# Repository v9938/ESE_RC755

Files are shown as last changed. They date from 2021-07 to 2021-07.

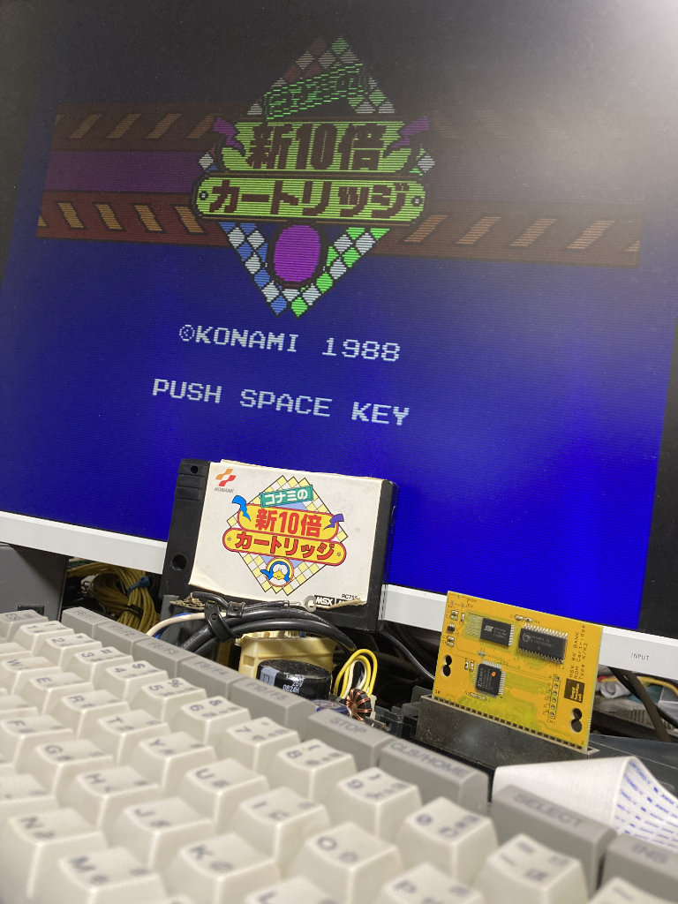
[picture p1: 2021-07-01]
photo01.jpg

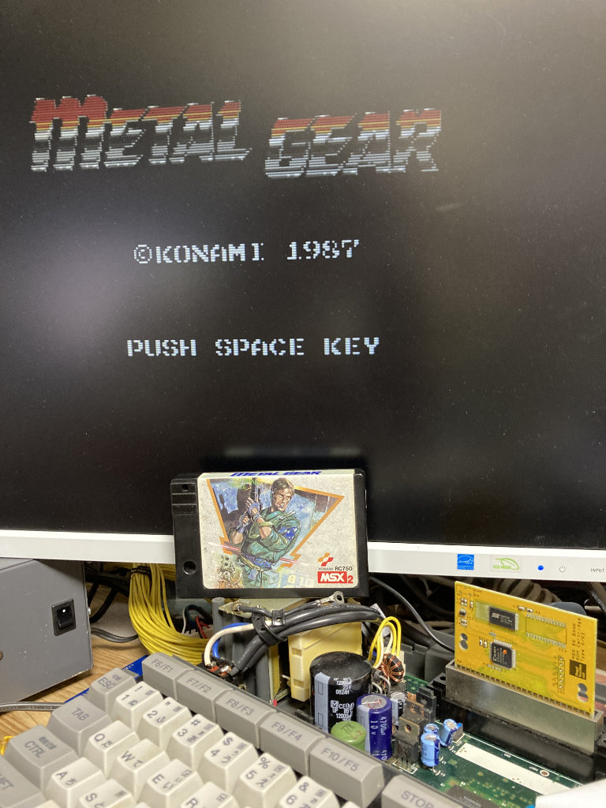
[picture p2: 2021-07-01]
photo02.jpg

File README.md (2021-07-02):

# MSX用カードリッジ KONAMI4互換<BR>Flashカードリッジ 似非RC755
KONAMI8Kバンク切り替え(KONAMI4)互換のカードリッジです。<BR>
KONAMI VRC007431互換のCPLDを搭載しており、「1Mbit+FRAM版」/「4Mbit版」 の2つのVersionがあります。<BR>
※SCCは付いていません。<BR>
<BR>
「1Mbit+FRAM版は、「新10倍カードリッジ」(GAME MASTER2)と同一バンク構成になっており、<BR>
 SRAMバッテリ切れの同カセットの救済用として使用する事ができます。<BR>
<BR>
各カセットは、Boothにて頒布しています。<BR>
https://ifc.booth.pm/items/3092101 
https://ifc.booth.pm/items/3092120

## ■ メモリマップ

KONAMI4と同様の仕様です。0x4000-5FFFの空間はBANK0固定なのに注意してください。

| Page (8kB) | Switching address | Initial segment | 
| --- | --- | --- |
| 4000h ~ 5FFFh  | 5000h (mirrors: 5001h ~ 57FFh) | 0  (FIXED) | 
| 6000h ~ 7FFFh  | 7000h (mirrors: 7001h ~ 77FFh) | 1 | 
| 8000h ~ 9FFFh  | 9000h (mirrors: 9001h ~ 97FFh) | 2 | 
| A000h ~ BFFFh  | B000h (mirrors: B001h ~ B7FFh) | 3 |

<BR>

| BIT7 | BIT6 | BIT5 | BIT4 | BIT3 | BIT2 | BIT1 | BIT0 |
| ---- | ---- | ---- | ---- | ---- | ---- | ---- | ---- |
| Unused | Unused | Segment[5] | Segment[4] | Segment[3] | Segment[2] | Segment[1] | Segment[0] |

Bit 0 ~ 5 = Segment number <BR>
Bit 6 ~ 7 = Unused <BR>
<BR>
F-RAMが有効の場合は下記の通りです。<BR>
| BIT7 | BIT6 | BIT5 | BIT4 | BIT3 | BIT2 | BIT1 | BIT0 |
| ---- | ---- | ---- | ---- | ---- | ---- | ---- | ---- |
| Unused | Unused | SRAM Segment | SRAM/ROM | Segment[3] | Segment[2] | Segment[1] | Segment[0] |

Bit 0 ~ 3 = Segment number <BR>
Bit 4 = 1 to select the SRAM (writable on page B000h ~ BFFFh only) <BR>
Bit 5 = SRAM segment select (two segments of 4kB available) <BR>
Bit 6 ~ 7 = Unused <BR>
<BR>
参考：
https://www.msx.org/wiki/MegaROM_Mappers#Game_Master_2_.28Konami.29

<BR>
下記Pageについては、Flash書き込みの為にBIT7 Flash controlが拡張されています。<BR>
  
| Page (8kB) | Switching address | Initial segment | 
| --- | --- | --- |
| A000h ~ BFFFh (mirror: 2000h ~ 3FFFh) | B000h (mirrors: B001h ~ B7FFh) | 3 |

<BR>
  
| BIT7 | BIT6 | BIT5 | BIT4 | BIT3 | BIT2 | BIT1 | BIT0 |
| ---- | ---- | ---- | ---- | ---- | ---- | ---- | ---- |
| Flash | Unused | Segment[5] | Segment[4] | Segment[3] | Segment[2] | Segment[1] | Segment[0] |

Bit 0 ~ 5 = Segment number <BR>
Bit 6 = Unused <BR>
Bit 7 = Flash control<BR>
<BR>
F-RAMが有効の場合は下記の通りです。<BR>
| BIT7 | BIT6 | BIT5 | BIT4 | BIT3 | BIT2 | BIT1 | BIT0 |
| ---- | ---- | ---- | ---- | ---- | ---- | ---- | ---- |
| Flash | Unused | SRAM Segment | SRAM/ROM | Segment[3] | Segment[2] | Segment[1] | Segment[0] |

Bit 0 ~ 3 = Segment number <BR>
Bit 4 = 1 to select the SRAM (writable on page B000h ~ BFFFh only) <BR>
Bit 5 = SRAM segment select (two segments of 4kB available) <BR>
Bit 6 = Unused <BR>
Bit 7 = Flash control<BR>
<BR>
## ■ Flashの制御方法
書き込みモードにするために、0xA000-BFFFに0x80を書き込んでください。<BR>
Flashのコントロールアドレス2AAAhは4AAAh・コントロールアドレス5555hは5555hにマッピングされます。<BR>
書き込みには6000h ~ 7FFFhの領域を使ってください。他の領域では書き込みができない可能性があります。<BR>
<BR>
本製品は従来使用していたAMD系のFlashではなく、SST系を使用しています。<BR>
CMD体系は、AMD系とほぼ同じなのですが、CMDアドレスが違います。<BR>
また、BUSYの出方などもAMD系と異なるため注意してください。<BR>
  
 | Page 4 | A000h - AFFFh (A000h used) set bit7 = 1'b1  |  Set Flash Write mode | 
 | ------ | ------------------------------------------- | ------------------ | 
 | Page 1 | 4000h - 4fffh = Flash Address 2000 - 2fffh (BA1) MSX:4AAAh  |  Flash:2AAAh |
 | Page 1 | 5000h - 5fffh = Flash Address 5000 - 5fffh (BA2) MSX:5555h  |  Flash:5555h |

CMD例：
1. Set Flash mode         : 0xA000 = 0x80
1. Page Select            : 0x6000 = Segment
1. Flash Byte-Program 1st : 0x5555 = 0xAA
1. Flash Byte-Program 2nd : 0x4AAA = 0x55
1. Flash Byte-Program 3rd : 0x5555 = 0xA0
1. Write Data             : 0x6000～0x7fff = data
1. Page Reselect          : 0x6000 = Segment

参考：
https://www.microchip.com/wwwproducts/en/SST39SF010A
<BR>

## ■ Flash書き込みプログラム
書き込みプログラムとして、eseRC755を同梱しています。 
いずれかのスロットに当該カードリッジを挿入し、以下コマンドを実行してください。<BR>
`>eseRC755.com [書き込みをしたいROM File]`<BR>
<BR>
ソースコードは、z88dkでコンパイル可能です。コンパイルオプションは下記になります。<BR>
`zcc +msx -create-app -subtype=msxdos -lmsxbios  main.c -o eseRC755.com`<BR>

## ■ 頒布基板について
「1Mbit+FRAM版」/「4Mbit版」 の2つのVersionがあります。<BR>
IC1にICが付いているのが「1Mbit+FRAM版」、ICが無いものが「4Mbit版」になります<BR>
<BR>
出荷時は検査用の動作プログラムが書き込んであります。<BR>
動作完了後、[e]キーを押すことで当該プログラムを消去する事が可能です。<BR>

J1をカットしてSW1を追加することで、ROMの切り離しが可能です。後差しが気になる場合に追加してください。<BR>
推奨パーツ：SW1 IS-1245T-G [Switronic] (秋月電子扱い）<BR>
<BR>
回路図およびガーバファイルが必要な場合は同梱ファイルを参考にしてください。<BR>
※ソフト頒布などで使用する場合はご相談頂ければ、別途製造対応可能です。<BR>
<BR>
## ■ CPLDについて
CPLD Xillix XC9536XLに書き込んであるデータは「1Mbit+FRAM版」/「4Mbit版」で異なります。<BR>
RTL上のUSE_MRAMを変更することでそれぞれのVersionを作成可能です。<BR>
<BR>

## ■ カードリッジシェルについて
推奨はRGRさんのTransparent Cartridge Shell for MSX Konami-styleになります。<BR>
https://retrogamerestore.com/store/msx_cart_shell/
<BR>
シェル同梱版も、上記製品を使用しています。<BR>
輸入と製造都合で若干の小傷がある場合があります。あらかじめご了承ください。<BR>
<BR>
頒布基板はASCII仕様のいくつかのシェルタイプに対応していますが、<BR>
すべてのタイプには対応していません。ご了承ください。<BR>

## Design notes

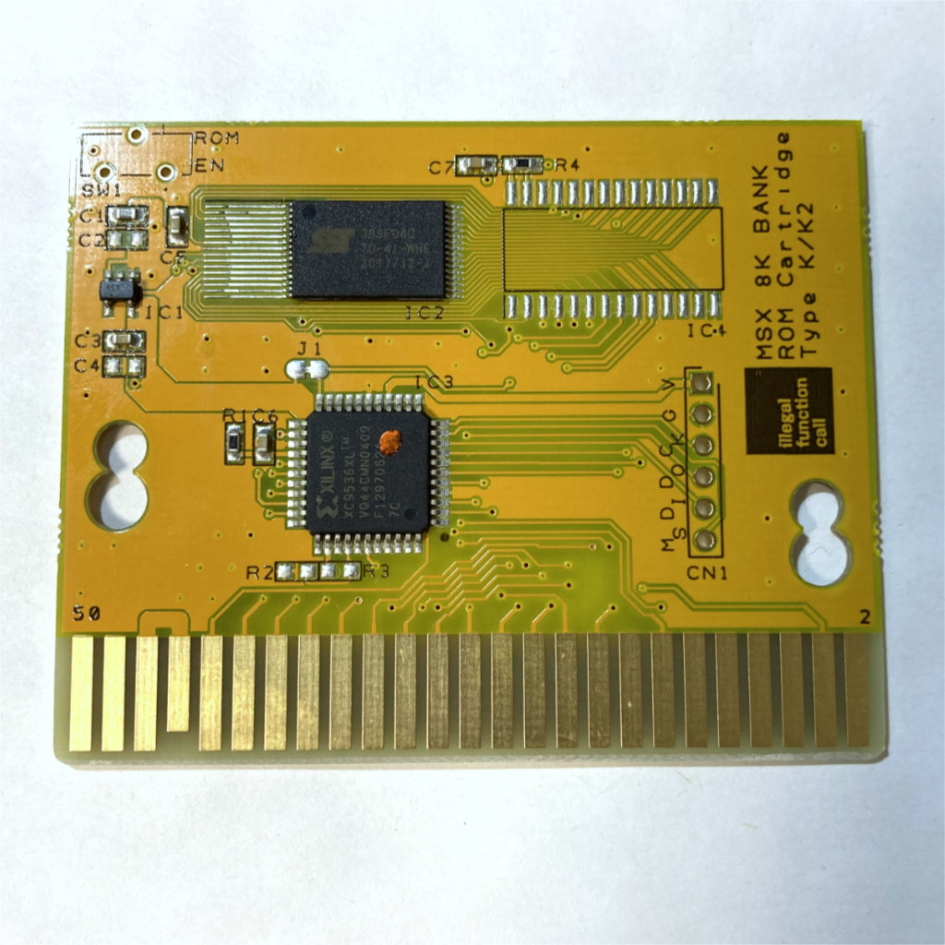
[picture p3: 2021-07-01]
PCB/PCBwoMRAM.jpg

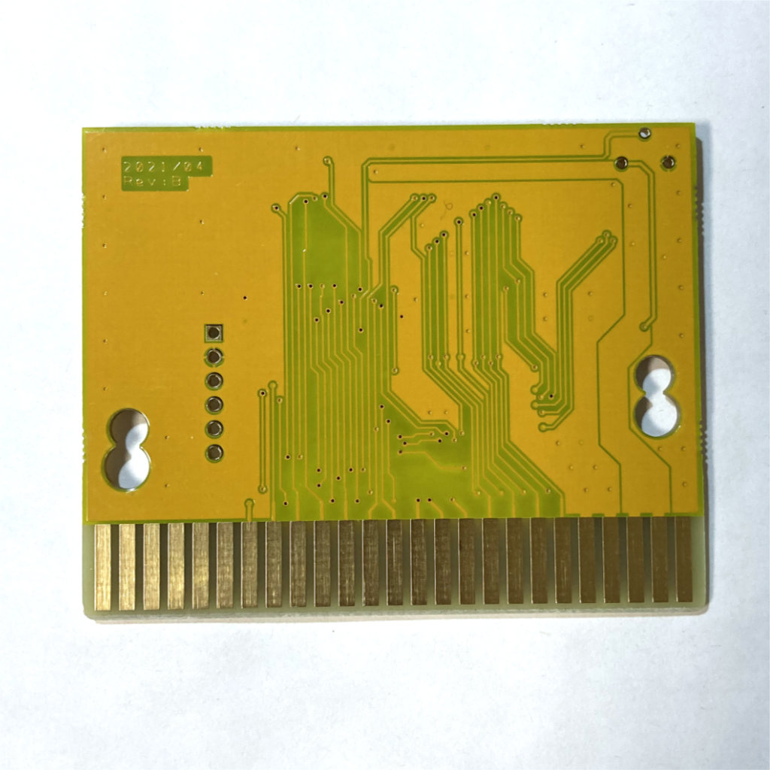
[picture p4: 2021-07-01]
PCB/PCBwMRAM2.jpg

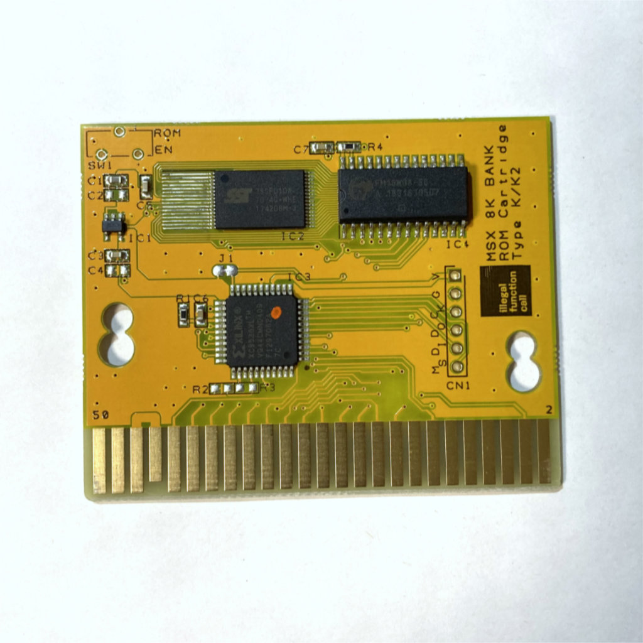
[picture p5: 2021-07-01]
PCB/PCBwMRAM.jpg

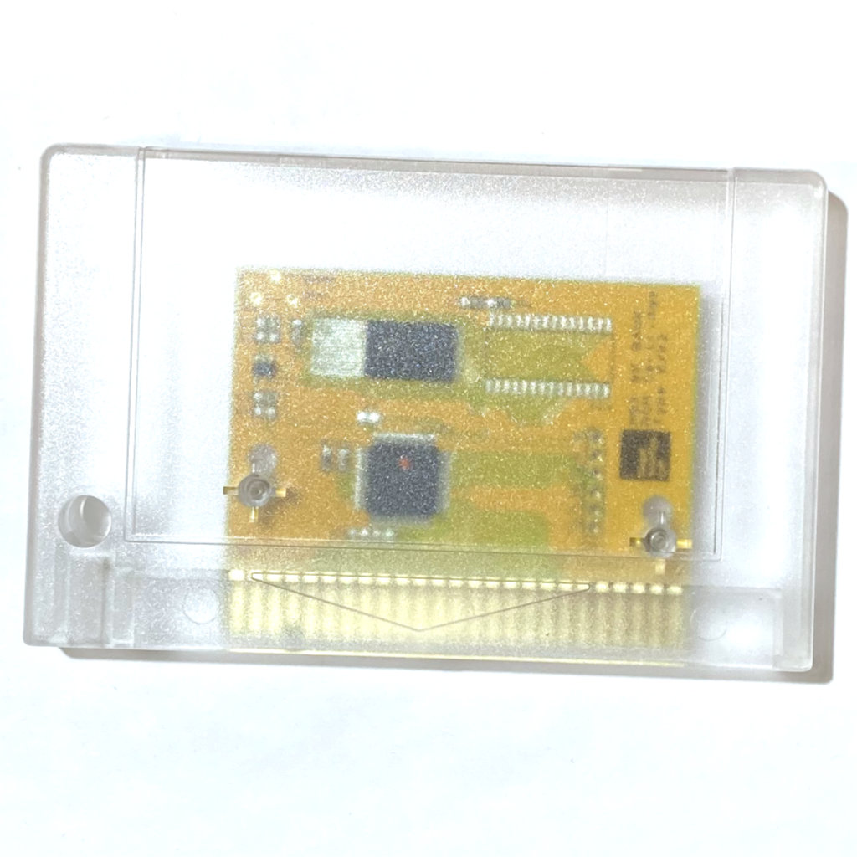
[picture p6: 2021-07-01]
PCB/PCBwoMRAM2.jpg

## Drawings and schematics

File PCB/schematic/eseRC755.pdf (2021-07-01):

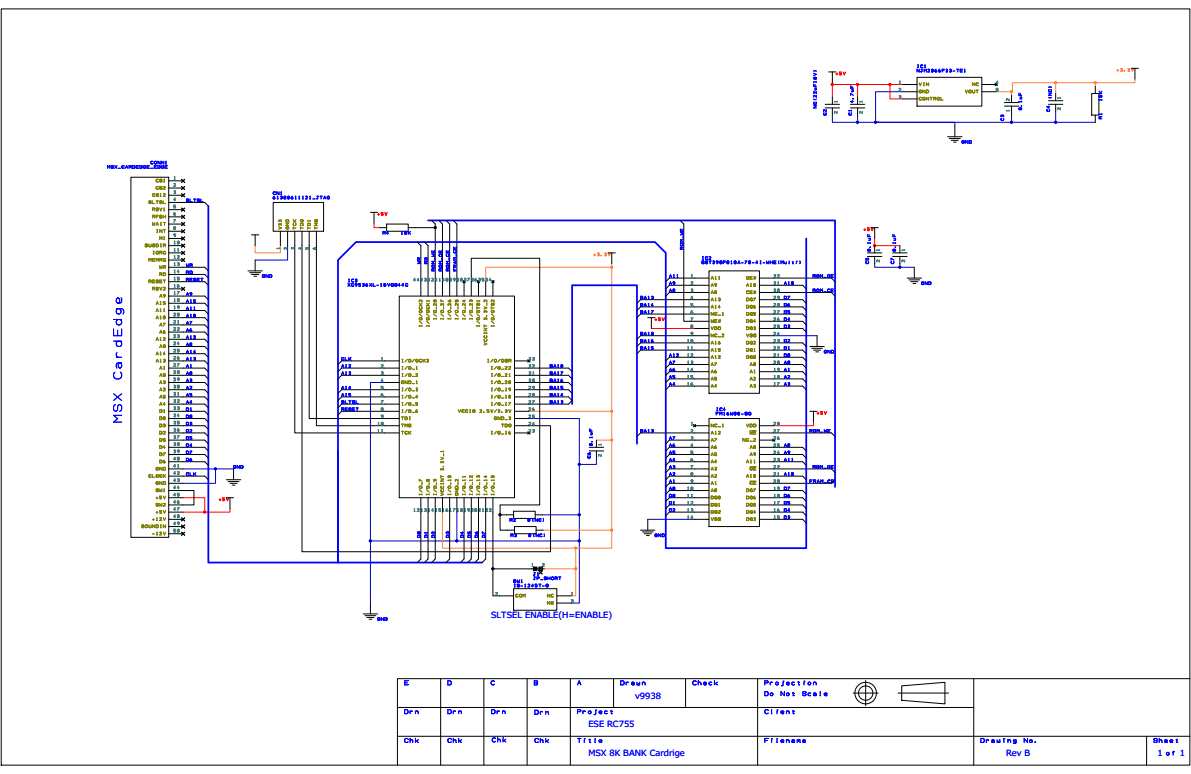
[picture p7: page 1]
ESE RC755; MSX 8K BANK Cardrige; Rev B

SLTSEL ENABLE(H=ENABLE)

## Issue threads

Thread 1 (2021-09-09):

Error with file eseRC755 - Drill Ident Drawing - [Through Hole]

tessmsx, 2021-09-09:
When uploading eseRC755 - Drill Ident Drawing - [Through Hole].gbr to PCB print it gives an error.
This file should be compatible with Gerber  RS-274x. Please, review it or upload compatible file.
Also, sharing source files would be very appreciated. Thank you.

v9938, 2021-09-09:
"Drill Ident Drawing" gerber data file will not normally be required for PCB manufacturing.
The file also includes the G04 command, which is not compatible with Gerber RS-274x.
However, many gerber viewers support the G04 command.
Therefore, I consider that this case does not need to be fixed.

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

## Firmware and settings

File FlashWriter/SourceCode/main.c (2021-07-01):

/*
	eseRC755 Flash ROM programmer
	Copyright 2021 @V9538
	
	V1.0		1st version
*/

#include <stdio.h>
#include <msx.h>
#include <sys/ioctl.h>

#define VERSION "V1.0"
#define DATE "2021/06"

#define BUF_SIZE 128

//Global
unsigned char SelectSlot;		//Select Slot number
unsigned char eseBank;			//eseRC755 6000-7fffh Bank number
unsigned char *addressWrite;	//Write pointer
unsigned char eseSlot;			//eseRC755 Slot number
unsigned char maxBank;			//ROM Size
int findId;						//Flash ID


//Assembler SubRoutine
void asmCalls(){
#asm
chengePageSlot:
	di
    ld a,(_SelectSlot)	;Slot Number

    ld hl,04000h		;Select page 1
    call 0024h			;call ENASLT

    ld a,(_SelectSlot)	;Slot Number
    ld hl,08000h		;Select page 2
    call 0024h			;call ENASLT

	ld hl,04AAAh		;Flash Address 1st 0x2AAA
	ld de,05555h		;Flash Address 2nd 0x5555

	ld a,(_eseBank)		;Bank Select 6000h-7fffh
	ld (06000h),a

	ld a,080h			;
    ld (0a000h),a		;eseRC755 Flash Bank mode
	ret

restoreRAMPage:
	ld a,003h			;
    ld (0a000h),a		;Exit eseRC755 Flash Bank mode

	ld a,(0f342h)		;Restore RAM Page (RAMAD1)
    ld hl,04000h		;Select page 1
    call 0024h			;call ENASLT

	ld a,(0f343h)		;Restore RAM Page (RAMAD2)
    ld hl,08000h		;Select page 2
    call 0024h			;call ENASLT
	ei
	ret
#endasm
}
void eraseEseRC755() __z88dk_fastcall __naked {
#asm
	call chengePageSlot
    
	ld a,0aah			; Chip-Erase Command 1st
    ld (de),a			; aa-55-80
	ld a,055h
    ld (hl),a
	ld a,080h
    ld (de),a

	ld a,0aah			; Chip-Erase Command 2nd
    ld (de),a			; aa-55-10
	ld a,055h
    ld (hl),a
	ld a,010h
    ld (de),a

	call restoreRAMPage

    ld hl,0fc9eh		;JIFFY address
	ld a,(hl)			;Load INTCNT
	add 06h				;16.6ms x 6 = 99.6ms
busyWait:
	cp	(hl)			;Check INTCNT
	jr nz,busyWait		;Wait Loop
	ret
#endasm
}

void writeEseRC755(unsigned char *bufferAddress)
{
#asm
	push hl					;Backup Buffer address
	call chengePageSlot		;4000-bfffh Change eseRC755 Slot 
	pop hl

	ld de,(_addressWrite)	;Get buffer address
	ld bc,BUF_SIZE			;Set buffer size
writeLoop:
	ld a,0aah				; Flash Byte-Program
    ld (05555h),a			; aa-55-a0
	ld a,055h
    ld (04AAAh),a
	ld a,0A0h
    ld (05555h),a
    ld a,(hl)				; Load Buffer Data
    ld (de),a				; Flash program data
	ld a,(_eseBank)			; Reselect Bank 6000h-7fffh
	ld (06000h),a
writeWait:	
    ld a,(de)				; Verify program data
    cp (hl)					; Verify check
    jr nz,writeWait			; Wait Byte-Program Time
	inc hl					; Buffer address ++
	inc de					; Flash address ++
	dec bc					; Counter --
	ld a,b					; bc == 00?
	or c 
    jr nz,writeLoop			; Continue loop
	ld (_addressWrite),de	
	call restoreRAMPage
	ret
#endasm
}

int chkEseRC755() __z88dk_fastcall __naked {
#asm
	call chengePageSlot	; 4000-bfffh Change eseRC755 Slot 

	ld a,0aah			; Software Product ID Entry aa-55-90-read0-1
    ld (de),a
	ld a,055h
    ld (hl),a
	ld a,090h
    ld (de),a
	ld a,(04000h)		; Read Maker ID
    ld b,a
	ld a,(04001h)		; Read Device ID
    ld c,a
	push bc				; Return value
	
	ld a,0aah			; Reset Command sequence aa-55-f0
    ld (de),a
	ld a,055h
    ld (hl),a
	ld a,0f0h
    ld (de),a

	call restoreRAMPage	; 4000-bfffh Restore RAM Slot
	pop hl
	ret
#endasm
}

void findEseRC755(void){
	unsigned char i;
	unsigned int chipId;
	
	if ((SelectSlot & 0xf0) == 0x80){
		//Expantion Slot Check
		for (i=0;i<4;i++){
			chipId = chkEseRC755();
			if ((chipId & 0xff00) == 0xbf00) {		//0xBF SST Maker ID
				eseSlot = SelectSlot;
				findId = chipId;
			}
			SelectSlot = SelectSlot + 4;
		}
	}else{
		//Master Slot Check
		chipId = chkEseRC755();
		if ((chipId & 0xff00) == 0xbf00) {			//0xBF SST Maker ID
			eseSlot = SelectSlot;
			findId = chipId;
		}
	}
}
	
int main(int argc,char *argv[])
{

	FILE *fp;
	unsigned char ReadData[BUF_SIZE];
	
	printf("eseRC755 Flash Writer %s\n",VERSION);
	printf("Copyrigth %s @v9938\n\n",DATE);

	if (argc<2){
		printf( "eseRC755 [rom files]\n");
		printf( "This program will write the selected file to the flash ROM.\n");
		return 0;
	}

	printf("Search Flash ... ");
	eseSlot = 0;
	//Slot 1 Search
	SelectSlot = *((unsigned char *)0xfcc2) | 0x01;		//EXPTBL (SLOT1)
	findEseRC755();
	//Slot 2 Search
	SelectSlot = *((unsigned char *)0xfcc3) | 0x02;		//EXPTBL (SLOT2)
	findEseRC755();
	//Slot 3 Search
	SelectSlot = *((unsigned char *)0xfcc4) | 0x03;		//EXPTBL (SLOT3)
	findEseRC755();

	if (eseSlot == 0) {								// Not find eseRC755
		printf("NOT find\n");
		printf("Bye...\n");
		return -1;
	}else{
		printf("Find!\n");
		printf("\nSlot: %02x",eseSlot);
	}

	//Flash Type Check
	printf("\nFlash Type: ");
	if ((findId & 0x00ff) == 0xb5){
		printf("SST39SF010A\n");
		maxBank = 0xf;
	}else if ((findId & 0x00ff) == 0xb6){
		printf("SST39SF020A\n");
		maxBank = 0x1f;
	}else if ((findId & 0x00ff) == 0xb7){
		printf("SST39SF040A\n");
		maxBank = 0x3f;
	}else{
		printf("Unknown Flash\n");
		printf("Bye...\n");
		return -1;
	}

	//ROM File Open
	fp =fopen(argv[1],"rb");
    if( fp == NULL ){
    	printf( "File can't open... %s\n", argv[1]);
    	return -1;
    }

	//Bank set
	SelectSlot = eseSlot;
	eseBank = 0;
	addressWrite = (unsigned char *)0x6000;

	//Flash Erase
	printf("\nFlash Erase ... ");
	eraseEseRC755();
	printf("Done.");

	//Flash Write
	printf("\nFlash Write");
	printf("\n     0123456789ABCDEF");
	printf("\n0x00 .");
	
	while (1){

		fread(ReadData,sizeof ReadData, 1, fp);		//Read Buffer

		if (feof(fp) != NULL) break;				//File End ?
		if (ferror(fp) != NULL) {					//EIO Error?
			printf("File IO Error!\n");
			fclose(fp);
			return -1;
		}

		//Parameter Check
		if (addressWrite >= 0x8000){					// 6000-7fffh Write finsh?
			addressWrite = (unsigned char *)0x6000;		// Yes! Return write start address
			if (eseBank < maxBank) {					// ROM size check?
				eseBank++;								// OK! write next bank
				if ((eseBank & 0x0f)== 0){				// Display progress
					printf("\n0x%02x .",eseBank);		//
				}else{
					printf(".");						// Display progress
				}

			}else{
				printf("\nROM size is FULL.");			// Ummm.ROM is FULL
				break;									//
			}
		}
		writeEseRC755(ReadData);						//Bank Write Data
	}
	fclose(fp);
	printf("\n\nDone. Thank you using!\n");
	return 0;

}

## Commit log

2021-06-30 Update README.md
    Update some information ,Flash write program/ about PCB /about Cardridge shell etc
2021-07-01 1st official release & Clean up files
    Added Flash Write tools & PCB Datas
    [eseRC755 - Bottom Copper (Resist).gbr, eseRC755 - Bottom Copper.gbr, eseRC755 - Drill Ident Drawing - [Through Hole].gbr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]
2022-11-16 Fixed missing drl file
    [eseRC755 - Drill Data - [Through Hole].drl]
